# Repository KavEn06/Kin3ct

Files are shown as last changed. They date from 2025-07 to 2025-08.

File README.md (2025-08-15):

# Kin3ct



## What is it?
Kin3ct is a handheld 3D scanner built around a Kinect v2 sensor and a Raspberry Pi 5. It’s designed to let you scan objects and spaces while seeing the point cloud build live on the screen, instead of waiting to process photos later with photogrammetry. The scanner will have a built‑in 7‑inch touchscreen so you can watch the scan as you move, along with a few shortcut buttons on the side to start/stop scanning and switch modes.  
Right now, the plan is to capture the raw data on the Pi and clean it up later on a PC for use in CAD, Blender, or other 3D software.

## Backstory / Why did I build it?
I’ve always thought 3D scanners were super cool, but most of the good ones are either huge, expensive, or both. At first I looked into doing photogrammetry, but it felt too slow — I really wanted something that could show what I was scanning *live*, so you can see if you missed a spot or need to rescan right away. That’s when I thought about using a Kinect v2 with a Raspberry Pi to make a handheld scanner that’s (sort of) portable and way cheaper than commercial scanners. It probably won’t be as accurate or polished, but the idea of being able to walk around an object and watch the point cloud build up on a little screen sounded too fun not to try.

## Hardware
- **Raspberry Pi 5**             – handles running RTAB‑Map and collecting the data
- **Kinect v2 + USB adapter**    – the depth sensor that actually does the scanning
- **7-inch LCD touchscreen**     – to see the point cloud build live while scanning
- **NVMe SSD**                   – extra storage for saving larger scans without swapping SD cards
- **Custom 4-button PCB**        – for shortcut controls (start/stop scan, switch modes, etc.)
- **3D printed case**            – inspired by the Revopoint Miraco so it’s easier to hold with two hands

## 3D Model





If anyone wants to take a peek at the CAD model, here’s the [Onshape document link](https://cad.onshape.com/documents/48930f9beb6214e895f71f2e/w/9f4ed8c437f438cf09a60f4e/e/15fc98493092e56e2661dd14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).

## Schematic and PCB 

<p align="center">
  
  
</p>

Interms of the wiring for the Kinect, it goes such as: 
Kinect -> Adapter -> Raspberry  5 
Power -> Adapter -> Raspberry Pi 5 and Kinect 

## Firmware 
For controlling the scanner, I made a small 4‑button PCB that connects directly to the GPIO pins on the Raspberry Pi.  
There will be a Python script running on the Pi can just watch for GPIO state changes and trigger the right RTAB‑Map commands or shortcut functions like:
- Start/stop scanning
- Switch scanning modes
- Reset/clear the current point cloud
- Maybe something else later on

For the actual scanning, I’m planning to run RTAB‑Map on the Raspberry Pi 5. RTAB‑Map is an open‑source SLAM (Simultaneous Localization and Mapping) library that can build a 3D point cloud *live while scanning*, which is exactly what I wanted from the start.

To get the Kinect v2 data into RTAB‑Map, I’ll be using libfreenect2 — an open‑source driver that lets Linux talk to the Kinect v2 over USB 3.  
There isn’t an official ARM build, but it *does* work on the Pi if you build it from source (thanks to the Pi 5’s faster CPU and USB 3.0 ports).

I’m mostly following this guide on Instructables:  
👉 [RGB‑D SLAM With Kinect on Raspberry Pi 4 (Buster / ROS)](https://www.instructables.com/RGB-D-SLAM-With-Kinect-on-Raspberry-Pi-4-Buster-RO/)  

The general plan:
- Build and install libfreenect2 on the Pi so the Kinect v2 can stream depth + RGB data  
- Set up RTAB‑Map (through ROS) to receive that data and do live SLAM
- Save the generated point clouds to the SSD for cleanup later on the PC

This way, the Pi handles the live scanning part, and I can do heavier mesh cleanup or conversions in Blender or MeshLab afterward.  

### BOM 
| Item | Purpose | Source | Price |
|---|---|---|---:|
| Raspberry Pi 5 | Main compute unit | [PiShop](https://www.pishop.ca/product/raspberry-pi-4-model-b-4gb/) | $84 |
| 7 inch LCD Display + Touch | Display & user interface | [AliExpress](https://www.aliexpress.com/item/1005006420023450.html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) | $40 |
| Kinect v2 + Adapter | Depth camera for scanning | Owned | $45 |
| Push Button | Physical controls (start/stop etc.) | [AliExpress](https://www.aliexpress.com/item/32815969627.html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) | $2 |
| Custom PCB | Connects buttons, SSD, etc.  | JLCPCB | $5 |
| 3D Printed Case | Holds everything together | Self-Sourced | $0 |
| NVMe SSD | Storage for scan data | Owned | $0 |
| | |Total CAD | $177 |
| | |Total USD | $128 |

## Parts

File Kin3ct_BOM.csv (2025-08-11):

Item | Purpose | Source | Price
Raspberry Pi 4 | Main compute unit | PiShop https://www.pishop.ca/product/raspberry-pi-4-model-b-4gb/ | $77
7 inch LCD Display + Touch | Display & user interface | AliExpress https://www.aliexpress.com/item/1005006420023450.html?srcSns=sns_Copy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 | $40
Kinect v2 + Adapter | Depth camera for scanning | Owned | $0
Push Button | Physical controls (start/stop etc.) | AliExpress https://www.aliexpress.com/item/32815969627.html?srcSns=sns_Copy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 | $2
Custom PCB | Connects buttons, SSD, etc. | JLCPCB | $5
3D Printed Case | Holds everything together | Self-Sourced | $0
NVMe SSD | Storage for scan data | Owned | $0
 |  | Total CAD | $124
 |  | Total USD | $90

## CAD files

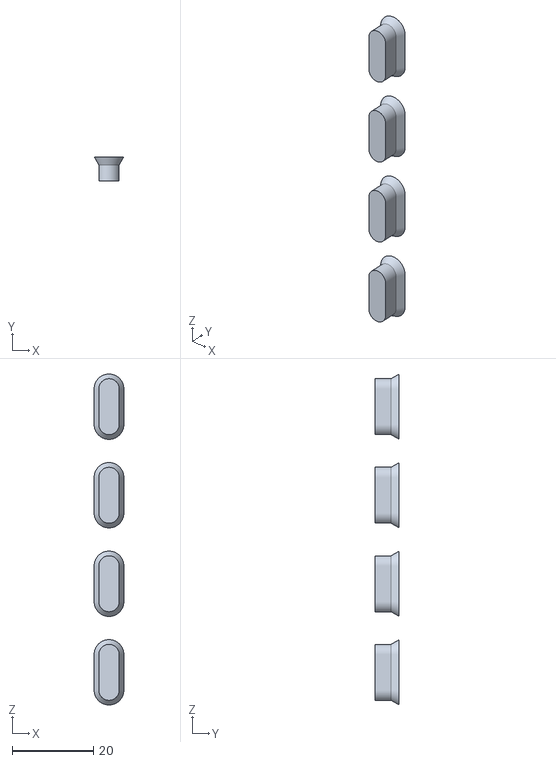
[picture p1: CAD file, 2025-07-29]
CAD/Buttons.stl
7.31 x 6.00 x 81.3

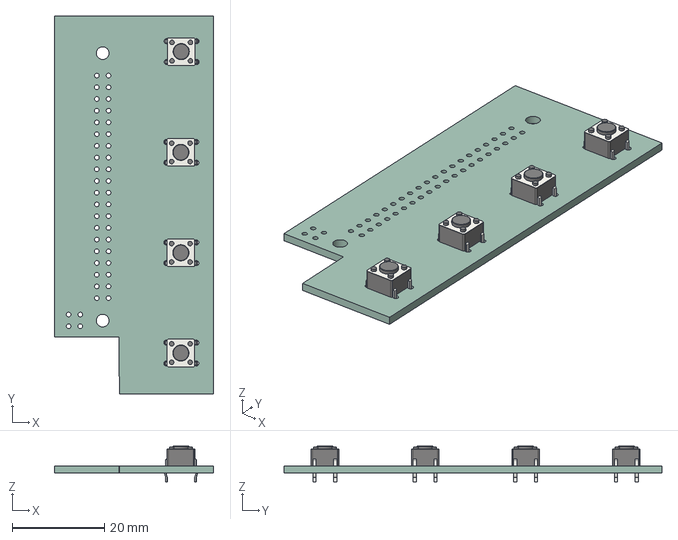
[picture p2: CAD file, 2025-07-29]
PCB/kin3ct.step
34.5 x 82.0 x 7.80 mm
SW_PUSH_6mm_H4.3mm x 4
kin3ct_PCB

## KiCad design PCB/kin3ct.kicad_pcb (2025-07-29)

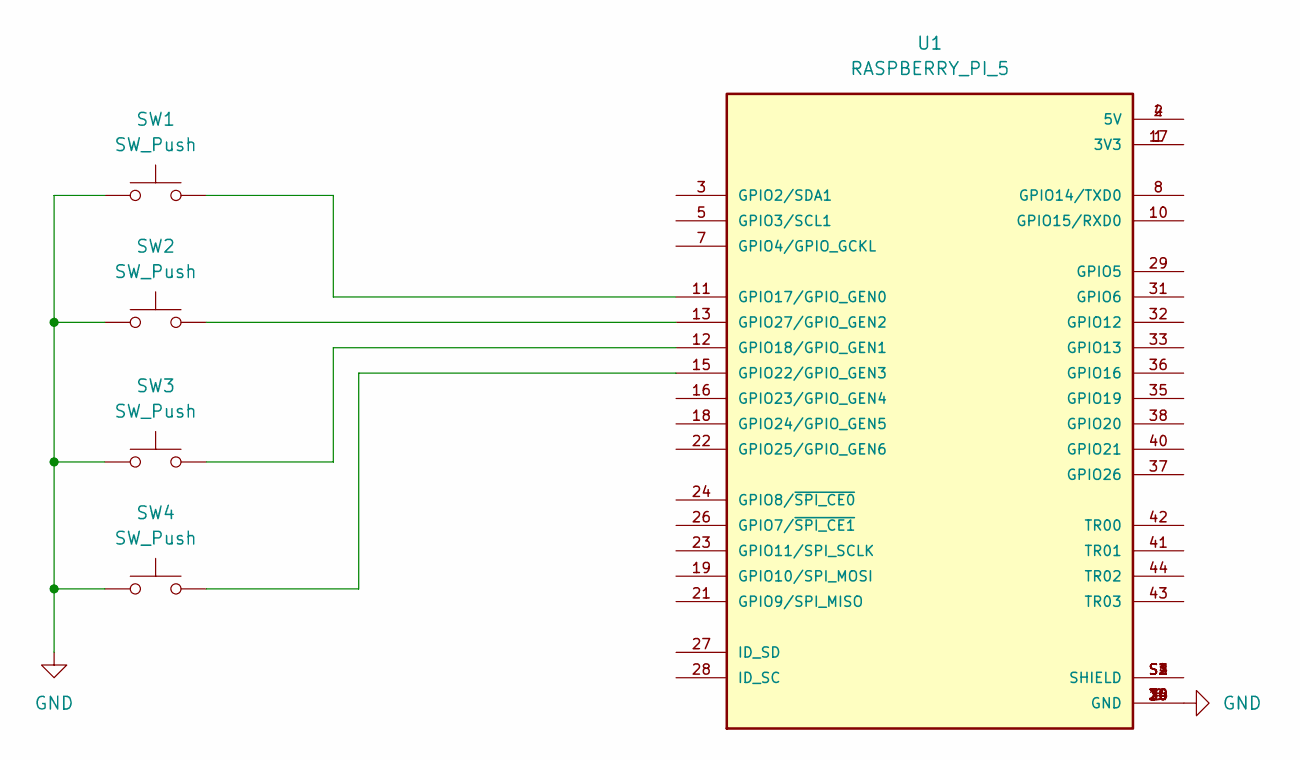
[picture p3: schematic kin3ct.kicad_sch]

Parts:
SW1, SW2, SW3, SW4: SW_Push; SW_PUSH_6mm_H4.3mm
U1: RASPBERRY_PI_5; MODULE_RASPBERRY_PI_4_MODEL_B_8G; PARTREV 4

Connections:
GND: SW1.1, SW2.1, SW3.1, SW4.1, U1.6 (GND), U1.9 (GND), U1.14 (GND), U1.20 (GND), U1.25 (GND), U1.30 (GND), U1.34 (GND), U1.39 (GND)
unnamed: U1.1 (3V3), U1.17 (3V3)
unnamed: U1.2 (5V), U1.4 (5V)
unnamed: SW1.2, U1.11 (GPIO17/GPIO_GEN0)
unnamed: SW3.2, U1.12 (GPIO18/GPIO_GEN1)
unnamed: SW4.2, U1.15 (GPIO22/GPIO_GEN3)
unnamed: SW2.2, U1.13 (GPIO27/GPIO_GEN2)
unnamed: U1.S1 (SHIELD), U1.S2 (SHIELD), U1.S3 (SHIELD), U1.S4 (SHIELD)

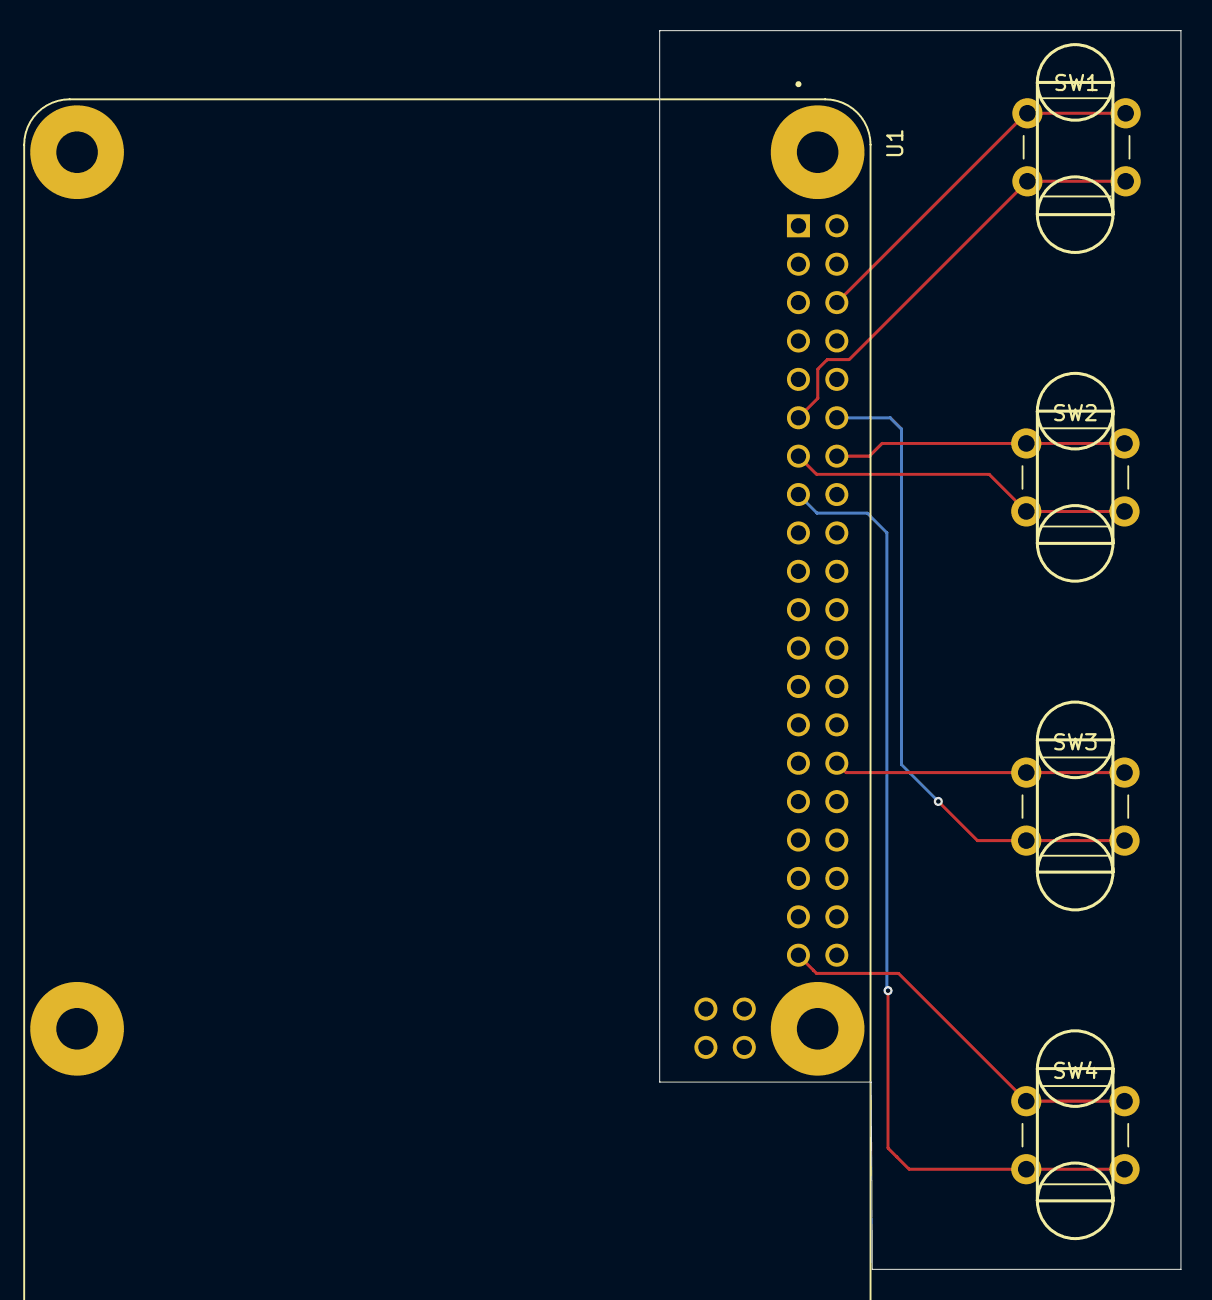
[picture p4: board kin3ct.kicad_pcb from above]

Board: 2 copper layers, 34.5 x 82.0 mm, 5 parts (0 on the bottom side), 8 nets.

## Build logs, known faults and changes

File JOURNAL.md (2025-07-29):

---
title: "Kin3ct"
author: "KavEn06"
description: "Handheld DIY 3D scanner that repurposes an Xbox Kinect and a Raspberry Pi"
created_at: "2025-07-20"
---

# Kin3ct Creation Journal 

# Total time spent: 17h

---
# July 20th – Can I even make this? Is this even possible?

Hi hi, this is my devlog/journal for my new idea: a **handheld 3D scanner** using a Kinect and Raspberry Pi!  

The idea is to build something like a portable(ish) 3D scanner that can capture point clouds **live while scanning**, so you can actually see what you’re scanning in real‑time, instead of just dumping a bunch of photos and waiting hours to process them later. That was the whole point from the start — not just “photogrammetry from a camera,” but an actual live‑processing scanner.

## **Early research / what I found:**
At first I thought about just using **photogrammetry**: take a video, import it later, and run it through Meshroom or COLMAP. But that doesn’t really fit the goal: I *want* the data to be processed live, so I can immediately see what I captured and clean it up later. So photogrammetry became more of a **backup option**, but not the main plan.

Then I found **Skanect**, which sounded promising: it can take data from a Kinect and build a mesh in real‑time. My idea was to run **Raspbian** on the Pi and install Skanect, using a Kinect driver like **libfreenect** to get the depth data. But after digging deeper, I realized Skanect (and pretty much every similar program) only runs on **x86** processors — not on **ARM**, which is what Raspberry Pis use. Same story for RecFusion, ReconstructMe, etc.

## **RTAB‑Maps! (MY SAVIOUR)**
After some more digging, I found **RTAB‑Map**, an open‑source SLAM and mapping library that *does* support ARM, and can work with the Kinect through **libfreenect2**. Even better, RTAB‑Map can do **live SLAM**: it builds a 3D map *while* you scan. Then I can import the point cloud later on my PC and clean it up properly for CAD or Blender.

So now the idea is:
- Use Kinect + Raspberry Pi 5 + RTAB‑Map + libfreenect2  
- Save maps to SSD or USB drive  
- Clean them up later on a real PC

## **Choosing the Kinect: v1 vs v2**
There are two main versions:  
- **Xbox 360 Kinect (v1)**  
- **Xbox One Kinect (v2)**


The Kinect v2 is better because:
- Higher resolution depth sensor
- Wider field of view
- Better depth accuracy and less noise

Downside: both require a special 12V power adapter to run over USB. It’s not a huge deal since adapters are available online, but it is an extra cost :/

## **Which RPi?**
I decided that the Raspberry Pi 5 would be my best option as, 
- It has way more processing power than Pi 4 → better for running RTAB‑Map
- USB 3.0 ports → needed to handle Kinect v2’s high bandwidth
- Can easily add an SSD for storage, which makes it practical to do lots of scans without swapping SD cards every time

## **Power challenge:**
The Kinect v2 is **very power hungry**. Making this completely battery‑powered (with step‑up converters) is possible, but battery life would probably be terrible. Having a cable for power isn’t the end of the world, since no one’s realistically going to use this to scan a whole house (and it obviously won’t be commercial grade anyway).



(This is how the adapter looks) 

## **Basicallyyy**
After digging through lots of dead ends, I finally landed on:
- Kinect v2 + Raspberry Pi 5
- RTAB‑Map to do live SLAM
- libfreenect2 as the driver
- Save to SSD, clean up on PC

**Total Time Spent Today: ~5h**
(Quite tragic that this took this long)

---

# July 21 – BOM and Starting CAD

Hi hi, devlog time again!

Today I spent a bit of time putting together an actual **BOM** so I could see roughly what this thing will cost and what parts I really need.  
The list isn’t final (obviously) but it helps me get an idea if it’s even reasonable before I get too carried away designing stuff.

### BOM (Unfinished)
| Item | Purpose | Source | Price |
|---|---|---|---:|
| Raspberry Pi 5 | Main compute unit | [PiShop](https://www.pishop.ca/product/raspberry-pi-5-4gb/?searchid=0&search_query=pi+5+) | $85 |
| 7 inch LCD Display + Touch | Display & user interface | [AliExpress](https://www.aliexpress.com/item/1005006420023450.html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) | $40 |
| Kinect v2 + Adapter | Depth camera for scanning | Self-Sourced | $60 |
| Push Button | Physical controls (start/stop etc.) | [AliExpress](https://www.aliexpress.com/item/32815969627.html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) | $2 |
| Custom PCB | Connects buttons, SSD, etc.  | JLCPCB | TBD |
| 3D Printed Case | Holds everything together | Self-Sourced | $0 |
| NVMe SSD | Storage for scan data | Owned | $0 |
|| | Total CAD | $187 |
|| | Total USD | $138 |

## CAD

After I got the BOM together, I started working in **Onshape** to see how this thing could actually look and come together.

I decided to take some inspiration from the Revopoint Miraco scanner, mainly because I really like that it’s a proper two‑handed scanner. It just seems way easier to hold steady and move around whatever you’re scanning, instead of trying to grip a box in one hand.



Here's the CAD model, it’s still *midway through*, but you can already see the vision I’m going for, kinda inspired by the Miraco scanner, with the two‑handed grip and the screen right in front. I feel like I have enough room to shove both the adapter and the Pi into the shell without any problems. 



I’ve just went with this model and kept refining it, and a couple hours later it’s starting to look quite polished now!!!! :D


<br>


**Total Time Spent Today: ~6h**

---

# July 22nd – more cad

Spent today doing more CAD stuff!  

First pic is just me turning the model into a proper shell with a wall thickness of 2.6mm, and I added standoffs for the Raspberry Pi and the screen. Also made sure all the parts actually fit inside (which they very clearly do so far, yay).  



Side note: the random yellow block in the model is just the Kinect adapter — I couldn’t find a proper CAD model for it, so that’s what its gonna be lol.

You might be wondering *“kavin where’s the Kinect gonna go?!?!?!”*  

It’s actually gonna go right at the bottom of the scanner, which is why i didn't do any fillets or anything down there so then it mates up nicely with the kinect.  

Here’s the model of the mount I made for it :D





**Total Time Spent Today: ~3h**

---

# July 23rd – even more cad

Today wasn’t much, I just decided to finish up this CAD model.  

I added ribs inside the shell where the grips are so it feels sturdier in the hand, and also added some buttons to the right side of the screen for easy control of shortcuts.  

It’s nothing huge, but it does make it feel more like a proper handheld scanner and less like just an empty box lol.







(IT'S ACTUALLY LOOKING LIKE A PROPER SCANNER WOOOOOOO) 

I also imported the sketch that I used to make the holes in the shell into KiCAD, so that I know where to place the push buttons on the PCB. (I just exported the sketch as a DXF and imported it into KiCAD's PCB editor)



**Total Time Spent Today: ~2h**

---

# July 28th – pcb and finishing steps

Made a simple 4‑button PCB today that connects straight to the Pi.  




I also imported it into Onshape so I could figure out the final position for the Pi inside the case. As you can see in the screenshot, everything lines up perfectly, but the USB headders on the Pi doesn't allow the Pi to get close enough to the PCB. 




I just put a small cutout in the corner of the pcb, which allowed me to move the Pi closer to the PCB by 6.7mm. (Which SHOULDDDD be close enough) 




**Total Time Spent Today: ~1h**

---

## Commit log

2025-07-29 cad files
    [Buttons.stl]
2025-07-29 pcb files
    [kin3ct.kicad_pcb, kin3ct.kicad_sch, kin3ct.step]
